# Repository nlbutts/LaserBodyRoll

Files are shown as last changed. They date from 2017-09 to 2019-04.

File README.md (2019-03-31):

# LaserBodyRoll

This product is designed to simulate wheel slip to prevent the front of a car from rising off the ground during hard acceleration. The device would be connected in between a wheel speed sensor and an engine ECU. Under normal conditions the device would pass through the wheel speed sensor directly to the engine ECU. If the front of the vehicle is detected rising off the ground, the system would increase the number of pulses per second (PPS) of the wheel to the engine ECU to simulate wheel slip. In theory, this should cause the engine ECU to reduce timing to prevent the simulated wheel slip and therefore reduce the front end from rising off the ground.
The system detects front end rise by using a laser rangefinder. The laser rangefinder can detect the small changes in distance from the mounting location to the ground. If the distance is increasing, then the system can increase the number of PPS from the wheel speed sensor to simulate the slip.

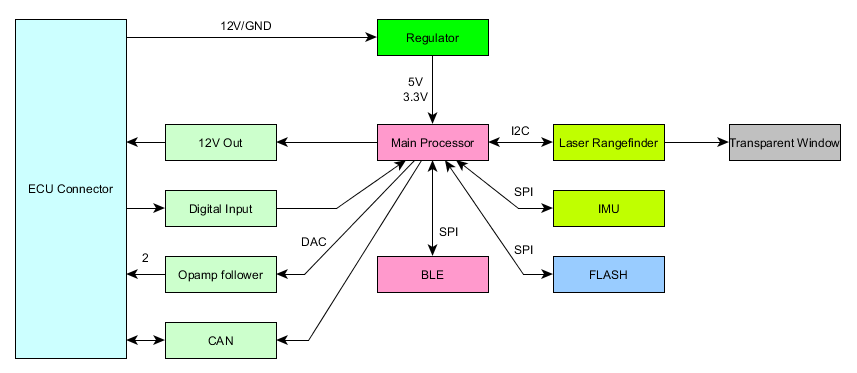
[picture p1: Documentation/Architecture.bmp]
Architecture High Level Architecture


# Hardware Connections
A single cable gland will be used to bring signals into and out of the ECU enclosure.

ECU Connector

| Wire | Description |
| --- | --- |
| Purple  | Power |
| Black  | Ground |
| Grey | Analog Out 1  |
| Red | Analog Out 2  |
| Brown  | DIN |
| Orange | DOUT |
| Yellow | CAN High |
| Green  | CAN Low |

The goal is to fit into this box enclosure

# Protocol between Processor and BLE
The PSoC and the Raspberry PI are connected via an SPI bus. The Pi is the SPI Master and the PSoC is a slave device. The packet that is transmitted to the PSOC is shown below

| Sync1 (8) | Sync2 (8) | Version (4)/Msg ID (4) | Length (8) | payload (2040) | CRC (8) |
| --- | --- | --- | --- | --- | --- |
| 0x55 | 0xAA | 0x01 / MSG ID | | | |

The number in parenthesis is how many bits are used for the various fields
The 4-bits of the version allows updates to the protocol. The 4-bits for the message ID allows
128 different message IDs. Length is the number of bytes in the payload 0-255 bytes.
The CRC is the CRC-8-CCITT using the following generator polynominal:
x^8 + x^2 + x + 1 (0x7)

| MSG ID | Description |
| --- | ---|
| 0 | Data input  |
| 1 | Data output |
| 2 | Main programming image |
| 3 | BLE programming image  |

Data input is a generic pass through message from the BLE interface to the main processor. The
data input is made up of an 8-bit UUID followed by the data item. Each data item has a unique
length, format, scale, etc. Data output is the same as data input, just going in the other
direction

| UUID | Description | Size (bytes) | Data type | Units |
| ---- | --- | --- | --- | ----- |
| 0 | Analog 1 slope | 4 | float | mm/mv |
| 1 | Analog 1 y offset | 4 | float | mv |
| 2 | Analog 2 slope | 4 | float | mm/mv |
| 3 | Analog 2 y offset | 4 | float | mv |
| 4 | Open drain pull up enbl | 1 | uint8 | bool  |
| 5 | Laser distance in mm | 2 | uint16 | mm |
| 6 | Accel X in mg | 2 | uint16 | mg |
| 7 | Accel Y in mg | 2 | uint16 | mg |
| 8 | Accel Z in mg | 2 | uint16 | mg |
| 9 | Gyro X in dps | 2 | uint16 | dps |
| 10 | Gyro Y in dps | 2 | uint16 | dps |
| 11 | Gyro Z in dps | 2 | uint16 | dps |
| 12 | Auto level gain | 4 | float | |
| 13 | EPOCH time | 4 | uint32 | epoch |
| 14 | Super cap voltage | 2 | uint32 | mv |

The main programming image is a LZMA compressed binary file. The BLE programming
image is an LZMA compressed cyacd file. Each BLE packet is only 23 bytes or so.
The programming images are transmitted with a byte counter as the first byte
of the payload. This allows a check that a packet hasn't been dropped and they are being
received in the correct order.

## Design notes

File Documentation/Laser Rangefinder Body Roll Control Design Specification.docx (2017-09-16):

# Laser Rangefinder Body Roll Control Design Specification

# Overview

This product is designed to simulate wheel slip to prevent the front of a car from rising off the ground during hard acceleration. The device would be connected in between a wheel speed sensor and an engine ECU. Under normal conditions the device would pass through the wheel speed sensor directly to the engine ECU. If the front of the vehicle is detected rising off the ground, the system would increase the number of pulses per second (PPS) of the wheel to the engine ECU to simulate wheel slip. In theory, this should cause the engine ECU to reduce timing to prevent the simulated wheel slip and therefore reduce the front end from rising off the ground.

The system detects front end rise by using a laser rangefinder. The laser rangefinder can detect the small changes in distance from the mounting location to the ground. If the distance is increasing, then the system can increase the number of PPS from the wheel speed sensor to simulate the slip.

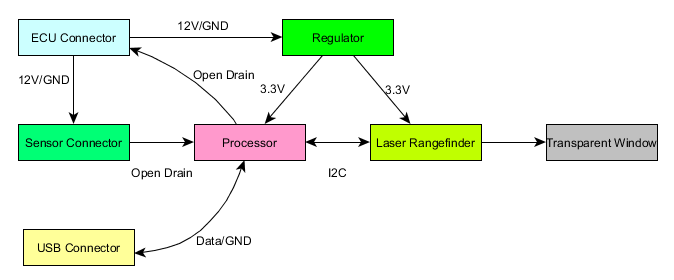
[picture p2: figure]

# Hardware Connections

The system will have three connectors: 1) to ECU connector, 2) to sensor connector, 3) USB connector. The ECU connector will supply power to the box, and provide the speed sensor signal back to the ECU. The sensor connector will provide power to the sensor and receive the PPS signal. The USB connector will be used for reprogramming and configuration.

ECU Connector

Pin | Description
1 | Power
2 | Ground
3 | Speed out
4 | Reserved

Sensor Connector

Pin | Description
1 | Power
2 | Ground
3 | Speed Input

USB Connector

Pin | Description
1 | VCC
2 | D-
3 | D+
4 | Ground

The device will consume no more than 1 watts of power (TBD). The device will be able to supply 0.5 watts to the sensor.

# Laser Rangefinder

A ST Microelectronics VL53L0 laser rangefinder. This device has a range of roughly 2 meters and can determine the distance down to a millimeter.

# Sensor Input/Output

The sensor input circuit will be able to handle an open drain style sensors. The sensor output system will drive an open drain style output.

# USB Port

The USB port will simulate a CDC interface and allow reprogramming of the device as well as configuration parameters.

Parameter | Description | Units
Distance Null Zone | Distance change to ignore from the laser rangefinder | Millimeters
Gain | Value multiplied by the change in distance to change in frequency
Averaging Filter | Long term averaging filter to capture baseline | Seconds

A PC tool will be written to allow these parameters to be changed.

# Theory of Operation

A long time filter will be used to determine the truth value of the ground. For example, over the course of 30 seconds the baseline distance will be determined. When the distance exceeds the Distance Null Zone, the Gain value will be multiplied by the difference between the Baseline value and the current distance value. This will be added to the current frequency of the wheel speed sensor.

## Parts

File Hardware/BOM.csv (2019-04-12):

Source: | C:\projects\LaserBodyRoll\Hardware\LaserBodyRoll.sch
Date: | 3/24/2019 14:10
Tool: | Eeschema (5.1.0)-1
Generator: | C:\Program Files\KiCad\bin\scripting\plugins/bom_csv_grouped_by_value.py
Component Count: | 42
Individual Components:
Item | Qty | Reference(s) | Value | LibPart | Footprint | Datasheet | Category | DK_Datasheet_Link | DK_Detail_Page | Description | Digi-Key_PN | Digikey | Family | MPN | Manufacturer | Partnum | Status
 |  | C1 | 10u | Device:C | Capacitors_SMD:C_0805_HandSoldering |  |  |  |  |  |  | 490-5523-1-ND |  |  |  | GRM21BR61E106KA73L
 |  | C2 | 10n | Device:C | Capacitors_SMD:C_0603_HandSoldering |  |  |  |  |  |  | 399-1092-1-ND |  |  |  | C0603C103J5RACTU
 |  | C3 | 10u | Device:C | Capacitors_SMD:C_0805_HandSoldering |  |  |  |  |  |  | 490-5523-1-ND |  |  |  | GRM21BR61E106KA73L
 |  | C4 | 0.1u | Device:C | Capacitors_SMD:C_0603_HandSoldering | ~
 |  | C5 | 22p | Device:C | Capacitors_SMD:C_0603_HandSoldering | ~
 |  | C6 | 22p | Device:C | Capacitors_SMD:C_0603_HandSoldering | ~
 |  | C7 | 0.1u | Device:C | Capacitors_SMD:C_0603_HandSoldering | ~
 |  | C8 | 0.1u | Device:C | Capacitors_SMD:C_0603_HandSoldering | ~
 |  | C9 | 0.1u | Device:C | Capacitors_SMD:C_0603_HandSoldering
 |  | C10 | 0.1u | Device:C | Capacitors_SMD:C_0603_HandSoldering | ~
 |  | C11 | 0.1u | Device:C | Capacitors_SMD:C_0603_HandSoldering
 |  | C12 | 2.2U | Device:C | Capacitors_SMD:C_0603_HandSoldering
 |  | C13 | 0.1u | Device:C | Capacitors_SMD:C_0603_HandSoldering
 |  | C14 | 10n | Device:C | Capacitors_SMD:C_0603_HandSoldering
 |  | C15 | 4.7u | Device:C | Capacitors_SMD:C_0603_HandSoldering
 |  | C16 | 0.1u | Device:C | Capacitors_SMD:C_0603_HandSoldering | ~
 |  | C17 | 0.1u | Device:C | Capacitors_SMD:C_0603_HandSoldering | ~
 |  | D1 | STPS2L40 | Device:D | Diodes_SMD:D_SMB |  |  |  |  |  |  | 497-5574-1-ND |  |  |  | STPS2L40U
 |  | D2 | D_TVS | Device:D_TVS | Diodes_SMD:D_SMB |  |  |  |  |  |  | 732-9779-1-ND |  |  |  | 824520201
 |  | D3 | D_TVS | Device:D_TVS | Diodes_SMD:D_SMB |  |  |  |  |  |  | 732-9779-1-ND |  |  |  | 824520201
 |  | D4 | D_Schottky | Device:D_Schottky | Diodes_SMD:D_SOD-123 |  |  |  |  |  |  | B0540W-FDICT-ND |  |  |  | B0540W-7-F
 |  | J1 | Conn_02x13_Odd_Even | Connector_Generic:Conn_02x13_Odd_Even | Pin_Headers:Pin_Header_Straight_2x13_Pitch2.54mm | ~
 |  | J2 | Conn_01x08 | Connector_Generic:Conn_01x08 | Pin_Headers:Pin_Header_Straight_1x08_Pitch2.54mm | ~
 |  | L1 | 4.7u | Device:L | Inductors_SMD:L_Taiyo-Yuden_MD-3030 |  |  |  |  |  |  | 490-15954-1-ND |  |  |  | LQH3NPN4R7MMEL
 |  | Q1 | Q_NPN_BCE | Device:Q_NPN_BCE | TO_SOT_Packages_SMD:SOT-23 |  |  |  |  |  |  | MMBT3904FSCT-ND
 |  | R1 | 24.3k | Device:R | Resistors_SMD:R_0603_HandSoldering
 |  | R2 | 24.3k | Device:R | Resistors_SMD:R_0603_HandSoldering
 |  | R3 | 24.3k | Device:R | Resistors_SMD:R_0603_HandSoldering
 |  | R4 | 49.9k | Device:R | Resistors_SMD:R_0603_HandSoldering
 |  | R5 | 9.53k | Device:R | Resistors_SMD:R_0603_HandSoldering
 |  | R6 | 10k | Device:R | Resistors_SMD:R_0603_HandSoldering
 |  | R7 | 10k | Device:R | Resistors_SMD:R_0603_HandSoldering
 |  | R8 | 120 | Device:R | Resistors_SMD:R_0603_HandSoldering | ~
 |  | R9 | 1k | Device:R | Resistors_SMD:R_0603_HandSoldering | ~
 |  | U1 | AOZ1280CI | dk_PMIC-Voltage-Regulators-DC-DC-Switching-Regulators:AOZ1280CI | digikey-footprints:SOT-23-6 | http://aosmd.com/res/data_sheets/AOZ1280CI.pdf | Integrated Circuits (ICs) | http://aosmd.com/res/data_sheets/AOZ1280CI.pdf | /product-detail/en/alpha-omega-semiconductor-inc/AOZ1280CI/785-1277-1-ND/2769845 | IC REG BUCK ADJ 1.2A SOT23-6 | 785-1277-1-ND |  | PMIC - Voltage Regulators - DC DC Switching Regulators | AOZ1280CI | Alpha & Omega Semiconductor Inc. |  | Active
 |  | U2 | ITS42K5D | General:ITS42K5D | KicadFootprint:PG-TSON-10 |  |  |  |  |  |  | ITS42K5DLDFXUMA1CT-ND |  |  |  | ITS42K5DLDFXUMA1
 |  | U3 | MCP47X | General:MCP47X | Housings_DFN_QFN:QFN-16-1EP_3x3mm_Pitch0.5mm |  |  |  |  |  |  | MCP47CVB22-E/MG-ND
 |  | U4 | ICM-20602 | General:ICM-20602 | Housings_DFN_QFN:QFN-16-1EP_3x3mm_Pitch0.5mm |  |  |  |  |  |  | 1428-1060-1-ND |  |  |  | ICM-20602
 |  | U5 | MCP25625 | General:MCP25625 | Housings_DFN_QFN:QFN-28-1EP_6x6mm_Pitch0.65mm |  |  |  |  |  |  | MCP25625T-E/MLCT-ND
 |  | U6 | VL53L0X | General:VL53L0X | KicadFootprint:VL53L0x |  |  |  |  |  |  | 497-16538-1-ND |  |  |  | VL53L0CXV0DH/1
 |  | U7 | LD3985 | General:LD3985 | TO_SOT_Packages_SMD:SOT-23-5_HandSoldering |  |  |  |  |  |  | 497-3504-1-ND
 |  | Y1 | 16MHz | Device:Crystal | Crystals:Crystal_SMD_5032-2pin_5.0x3.2mm_HandSoldering | ~
Collated Components:
Item | Qty | Reference(s) | Value | LibPart | Footprint | Datasheet | Category | DK_Datasheet_Link | DK_Detail_Page | Description | Digi-Key_PN | Digikey | Family | MPN | Manufacturer | Partnum | Status
1 | 2 | C1, C3 | 10u | Device:C | Capacitors_SMD:C_0805_HandSoldering |  |  |  |  |  |  | 490-5523-1-ND |  |  |  | GRM21BR61E106KA73L
2 | 2 | C2, C14 | 10n | Device:C | Capacitors_SMD:C_0603_HandSoldering |  |  |  |  |  |  | 399-1092-1-ND |  |  |  | C0603C103J5RACTU
3 | 9 | C4, C7, C8, C9, C10, C11, C13, C16, C17 | 0.1u | Device:C | Capacitors_SMD:C_0603_HandSoldering | ~
4 | 2 | C5, C6 | 22p | Device:C | Capacitors_SMD:C_0603_HandSoldering | ~
5 | 1 | C12 | 2.2U | Device:C | Capacitors_SMD:C_0603_HandSoldering
6 | 1 | C15 | 4.7u | Device:C | Capacitors_SMD:C_0603_HandSoldering
7 | 1 | D1 | STPS2L40 | Device:D | Diodes_SMD:D_SMB |  |  |  |  |  |  | 497-5574-1-ND |  |  |  | STPS2L40U
8 | 2 | D2, D3 | D_TVS | Device:D_TVS | Diodes_SMD:D_SMB |  |  |  |  |  |  | 732-9779-1-ND |  |  |  | 824520201
9 | 1 | D4 | D_Schottky | Device:D_Schottky | Diodes_SMD:D_SOD-123 |  |  |  |  |  |  | B0540W-FDICT-ND |  |  |  | B0540W-7-F
10 | 1 | J1 | Conn_02x13_Odd_Even | Connector_Generic:Conn_02x13_Odd_Even | Pin_Headers:Pin_Header_Straight_2x13_Pitch2.54mm | ~
11 | 1 | J2 | Conn_01x08 | Connector_Generic:Conn_01x08 | Pin_Headers:Pin_Header_Straight_1x08_Pitch2.54mm | ~
12 | 1 | L1 | 4.7u | Device:L | Inductors_SMD:L_Taiyo-Yuden_MD-3030 |  |  |  |  |  |  | 490-15954-1-ND |  |  |  | LQH3NPN4R7MMEL
13 | 1 | Q1 | Q_NPN_BCE | Device:Q_NPN_BCE | TO_SOT_Packages_SMD:SOT-23 |  |  |  |  |  |  | MMBT3904FSCT-ND
14 | 3 | R1, R2, R3 | 24.3k | Device:R | Resistors_SMD:R_0603_HandSoldering
15 | 1 | R4 | 49.9k | Device:R | Resistors_SMD:R_0603_HandSoldering
16 | 1 | R5 | 9.53k | Device:R | Resistors_SMD:R_0603_HandSoldering
17 | 2 | R6, R7 | 10k | Device:R | Resistors_SMD:R_0603_HandSoldering
18 | 1 | R8 | 120 | Device:R | Resistors_SMD:R_0603_HandSoldering | ~
19 | 1 | R9 | 1k | Device:R | Resistors_SMD:R_0603_HandSoldering | ~
20 | 1 | U1 | AOZ1280CI | dk_PMIC-Voltage-Regulators-DC-DC-Switching-Regulators:AOZ1280CI | digikey-footprints:SOT-23-6 | http://aosmd.com/res/data_sheets/AOZ1280CI.pdf | Integrated Circuits (ICs) | http://aosmd.com/res/data_sheets/AOZ1280CI.pdf | /product-detail/en/alpha-omega-semiconductor-inc/AOZ1280CI/785-1277-1-ND/2769845 | IC REG BUCK ADJ 1.2A SOT23-6 | 785-1277-1-ND |  | PMIC - Voltage Regulators - DC DC Switching Regulators | AOZ1280CI | Alpha & Omega Semiconductor Inc. |  | Active
21 | 1 | U2 | ITS42K5D | General:ITS42K5D | KicadFootprint:PG-TSON-10 |  |  |  |  |  |  | ITS42K5DLDFXUMA1CT-ND |  |  |  | ITS42K5DLDFXUMA1
22 | 1 | U3 | MCP47X | General:MCP47X | Housings_DFN_QFN:QFN-16-1EP_3x3mm_Pitch0.5mm |  |  |  |  |  |  | MCP47CVB22-E/MG-ND
23 | 1 | U4 | ICM-20602 | General:ICM-20602 | Housings_DFN_QFN:QFN-16-1EP_3x3mm_Pitch0.5mm |  |  |  |  |  |  | 1428-1060-1-ND |  |  |  | ICM-20602
24 | 1 | U5 | MCP25625 | General:MCP25625 | Housings_DFN_QFN:QFN-28-1EP_6x6mm_Pitch0.65mm |  |  |  |  |  |  | MCP25625T-E/MLCT-ND
25 | 1 | U6 | VL53L0X | General:VL53L0X | KicadFootprint:VL53L0x |  |  |  |  |  |  | 497-16538-1-ND |  |  |  | VL53L0CXV0DH/1
26 | 1 | U7 | LD3985 | General:LD3985 | TO_SOT_Packages_SMD:SOT-23-5_HandSoldering |  |  |  |  |  |  | 497-3504-1-ND
27 | 1 | Y1 | 16MHz | Device:Crystal | Crystals:Crystal_SMD_5032-2pin_5.0x3.2mm_HandSoldering | ~

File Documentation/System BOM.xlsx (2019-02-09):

Source: | C:\projects\LaserBodyRoll\Hardware\LaserBodyRoll.sch
Date: | 2018-03-07 05:57
Tool: | Eeschema (2017-09-19 revision dddaa7e69)-makepkg
Generator: | bom_csv_grouped_by_value.py
Component Count: | 84
Individual Components:
Item | Qty | Reference(s) | Manufacturer | Value | Footprint | Datasheet | Digikey | Partnum
 |  | C1 |  | 10u | Capacitors_SMD:C_0603 |  | 490-12737-1-ND
 |  | C2 |  | 3.3n | Capacitors_SMD:C_0603 |  | 1276-1790-1-ND | CL10C3R3CB8NNNC
 |  | C3 |  | 22u | SMD_Packages:SMD-1210_Pol |  | 478-9063-1-ND | TPSB226K006R0375
 |  | C4 |  | 1u | Capacitors_SMD:C_0603
 |  | C5 |  | 2.2U | Capacitors_SMD:C_0603
 |  | C6 |  | 20p | Capacitors_SMD:C_0603
 |  | C7 |  | 20p | Capacitors_SMD:C_0603
 |  | C8 |  | 6.8 | Capacitors_SMD:C_0603
 |  | C9 |  | 6.8 | Capacitors_SMD:C_0603
 |  | C10 |  | 1.5F | KicadFootprint:Elna_Dynacap |  | 604-1151-ND | DB-5R5D155T
 |  | C11 |  | 4.7u | Capacitors_SMD:C_0603
 |  | C12 |  | 100n | Capacitors_SMD:C_0603
 |  | C13 |  | 100n | Capacitors_SMD:C_0603
 |  | C14 |  | 100n | Capacitors_SMD:C_0603
 |  | C15 |  | 100n | Capacitors_SMD:C_0603
 |  | C16 |  | 1u | Capacitors_SMD:C_0603
 |  | C17 |  | 10n | Capacitors_SMD:C_0603
 |  | C18 |  | 10n | Capacitors_SMD:C_0603
 |  | C19 |  | 10n | Capacitors_SMD:C_0603
 |  | C20 |  | 0.1n | Capacitors_SMD:C_0603
 |  | C21 |  | 0.1u | Capacitors_SMD:C_0603_HandSoldering
 |  | C22 |  | 0.1u | Capacitors_SMD:C_0603_HandSoldering
 |  | C23 |  | 1u | Capacitors_SMD:C_0603_HandSoldering
 |  | C24 |  | 0.1u | Capacitors_SMD:C_0603
 |  | C25 |  | 2.2U | Capacitors_SMD:C_0603
 |  | C26 |  | 10n | Capacitors_SMD:C_0603
 |  | C27 |  | 4.7u | Capacitors_SMD:C_0603
 |  | D1 |  | STPS2L40 | Diodes_SMD:D_SMB |  | 497-5574-1-ND | STPS2L40U
 |  | D2 |  | D_TVS | Diodes_SMD:D_SMB |  | 732-9779-1-ND | 824520201
 |  | D3 |  | D | Diodes_SMD:D_SOD-123 |  | B0540W-FDICT-ND | B0540W-7-F
 |  | D4 |  | D_Zener | Diodes_SMD:D_SMB |  | MMSZ5232B-FDICT-ND | MMSZ5232B
 |  | D5 |  | D_Zener | Diodes_SMD:D_SMB |  | MMSZ5232B-FDICT-ND | MMSZ5232B
 |  | D6 |  | D_TVS | Diodes_SMD:D_SMB |  | 732-9779-1-ND | 824520201
 |  | D7 |  | LED_RABG | KicadFootprint:CREE_PLCC4 |  | CLV1L-FKB-CHMMQEHBB7673673CT-ND | CLV1L-FKB-CHMMQEHBB7673673
 |  | D8 |  | LED_RABG | KicadFootprint:CREE_PLCC4 |  | CLV1L-FKB-CHMMQEHBB7673673CT-ND | CLV1L-FKB-CHMMQEHBB7673673
 |  | J2 |  | FTSH-105-01-L-DV-K | KicadFootprint:FTSH-105-01-L-DV-K |  | SAM8799-ND
 |  | J3 |  | FTSH-105-01-L-DV-K | KicadFootprint:FTSH-105-01-L-DV-K |  | SAM8799-ND
 |  | J4 |  | Conn_01x08 | Pin_Headers:Pin_Header_Straight_1x08_Pitch2.54mm
 |  | L1 |  | L_Core_Ferrite | Inductors_SMD:L_0805 |  | 490-5988-1-ND | BLM21PG331SN1D
 |  | Q1 |  | Q_NPN_BCE | TO_SOT_Packages_SMD:SOT-23 |  | MMBT3904FSCT-ND
 |  | R1 |  | 525k | Resistors_SMD:R_0805 |  | 311-523KHRCT-ND
 |  | R2 |  | 100k | Resistors_SMD:R_0805 |  | P100KGCT-ND
 |  | R3 |  | 360 | Resistors_SMD:R_0603
 |  | R4 |  | 120 | Resistors_SMD:R_0603
 |  | R5 |  | 0 | Resistors_SMD:R_0603
 |  | R6 |  | 0 | Resistors_SMD:R_0603
 |  | R7 |  | 0 | Resistors_SMD:R_0603
 |  | R8 |  | 0 | Resistors_SMD:R_0603
 |  | R9 |  | 10k | Resistors_SMD:R_0603
 |  | R10 |  | 75k | Resistors_SMD:R_0603
 |  | R11 |  | 24.3k | Resistors_SMD:R_0603 |  | P10KGCT-ND
 |  | R12 |  | 24.3k | Resistors_SMD:R_0603
 |  | R13 |  | 24.3k | Resistors_SMD:R_0603
 |  | R14 |  | 24.3k | Resistors_SMD:R_0603 |  | 311-30KGRCT-ND
 |  | R15 |  | 24.3k | Resistors_SMD:R_0603 |  | 311-24.3KHRCT-ND
 |  | R16 |  | 24.3k | Resistors_SMD:R_0603
 |  | R17 |  | 24.3k | Resistors_SMD:R_0603
 |  | R18 |  | 24.3k | Resistors_SMD:R_0603
 |  | R19 |  | 24.3k | Resistors_SMD:R_0603
 |  | R20 |  | 330 | Resistors_SMD:R_0603
 |  | R21 |  | 330 | Resistors_SMD:R_0603
 |  | R22 |  | 330 | Resistors_SMD:R_0603
 |  | R23 |  | 1.7k | Resistors_SMD:R_0603
 |  | R24 |  | 1.7k | Resistors_SMD:R_0603
 |  | R25 |  | 10k | Resistors_SMD:R_0603
 |  | R26 |  | 10k | Resistors_SMD:R_0603
 |  | R27 |  | 25 | Resistors_SMD:R_0603
 |  | R28 |  | 330 | Resistors_SMD:R_0603
 |  | R29 |  | 330 | Resistors_SMD:R_0603
 |  | R30 |  | 330 | Resistors_SMD:R_0603
 |  | R31 |  | 120 | Resistors_SMD:R_0603
 |  | U1 |  | TPS821XX | KicadFootprint:TPS821XX |  | 296-47090-1-ND | TPS82150
 |  | U2 |  | LDK130-ADJ_SOT23_SOT353 | TO_SOT_Packages_SMD:SOT-353_SC-70-5 |  | 497-14023-2-ND | LDK130-M-R
 |  | U3 |  | STM32F303RETx | Housings_QFP:TQFP-64_10x10mm_Pitch0.5mm |  | 604-1151-ND | DB-5R5D155T
 |  | U4 |  | LMC6032 | SMD_Packages:SOIC-8-N |  | LMC6032IMX/NOPBDKR-ND | LMC6032IMX/NOPB
 |  | U5 |  | ITS42K5D | KicadFootprint:PG-TSON-10 |  | ITS42K5DLDFXUMA1CT-ND | ITS42K5DLDFXUMA1
 |  | U6 |  | CYBLE-022001-00 | KicadFootprint:CYBLE-022001 |  | 428-3408-1-ND | CYBLE-022001-00
 |  | U7 |  | TJA1051T-3 | Housings_SOIC:SOIC-8_3.9x4.9mm_Pitch1.27mm |  | 568-8684-1-ND | TJA1051T/3,118
 |  | U8 |  | ICM-20602 | KicadFootprint:QFN-16-no_center_3x3mm_Pitch0.5mm |  | 1428-1060-1-ND | ICM-20602
 |  | U9 |  | W25Qxx | Housings_SOIC:SOIC-8_3.9x4.9mm_Pitch1.27mm |  | W25Q64JVSSIQ-ND | W25Q64JVSSIQ
 |  | U10 |  | VL53L0X | KicadFootprint:VL53L0x |  | 497-16538-1-ND | VL53L0CXV0DH/1
 |  | W1 |  | TEST_1P | Connectors_TestPoints:Test_Point_Pad_d2.0mm
 |  | Y1 |  | 8MHz | Crystals:Crystal_SMD_MicroCrystal_CC4V-T1A-2pin_5.0x1.9mm_HandSoldering |  | 535-10630-1-ND | ABM3-8.000MHZ-D2Y-T
 |  | Y2 |  | 32.768 | Crystals:Crystal_SMD_MicroCrystal_CC7V-T1A-2pin_3.2x1.5mm_HandSoldering |  | 1253-1112-1-ND | ST3215SB32768B0HPWB3
 |  |  | Bud Industries |  |  |  | 377-1255-ND | PN-1321-C

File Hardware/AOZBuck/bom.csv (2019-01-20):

Source: | C:\projects\LaserBodyRoll\Hardware\AOZBuck\AOZBuck.sch
Date: | 6/24/2018 8:24:19 AM
Tool: | Eeschema (2017-09-19 revision dddaa7e69)-makepkg
Generator: | bom_csv_grouped_by_value.py
Component Count: | 10
Individual Components:
Item | Qty | Reference(s) | Value | LibPart | Footprint | Datasheet | Category | DK_Datasheet_Link | DK_Detail_Page | Description | Digi-Key_PN | Digikey | Family | MPN | Manufacturer | Partnum | Status
 |  | C1 | 10u | device:C | Capacitors_SMD:C_0805_HandSoldering |  |  |  |  |  |  | 490-5523-1-ND |  |  |  | GRM21BR61E106KA73L
 |  | C2 | 10n | device:C | Capacitors_SMD:C_0603_HandSoldering |  |  |  |  |  |  | 399-1092-1-ND |  |  |  | C0603C103J5RACTU
 |  | C3 | 10u | device:C | Capacitors_SMD:C_0805_HandSoldering |  |  |  |  |  |  | 490-5523-1-ND |  |  |  | GRM21BR61E106KA73L
 |  | D1 | D_Schottky | device:D_Schottky | Diodes_SMD:D_SOD-123 |  |  |  |  |  |  | B0540W-FDICT-ND |  |  |  | B0540W-7-F
 |  | J1 | Conn_01x02 | conn:Conn_01x02 | Pin_Headers:Pin_Header_Straight_1x02_Pitch2.54mm
 |  | J2 | Conn_01x02 | conn:Conn_01x02 | Pin_Headers:Pin_Header_Straight_1x02_Pitch2.54mm
 |  | L1 | 4.7u | device:L | Inductors_SMD:L_Taiyo-Yuden_MD-3030 |  |  |  |  |  |  | 490-15954-1-ND |  |  |  | LQH3NPN4R7MMEL
 |  | R1 | 49.9k | device:R | Resistors_SMD:R_0603_HandSoldering
 |  | R2 | 9.53k | device:R | Resistors_SMD:R_0603_HandSoldering
 |  | U1 | AOZ1280CI | dk_PMIC-Voltage-Regulators-DC-DC-Switching-Regulators:AOZ1280CI | digikey-footprints:SOT-23-6 | http://aosmd.com/res/data_sheets/AOZ1280CI.pdf | Integrated Circuits (ICs) | http://aosmd.com/res/data_sheets/AOZ1280CI.pdf | /product-detail/en/alpha-omega-semiconductor-inc/AOZ1280CI/785-1277-1-ND/2769845 | IC REG BUCK ADJ 1.2A SOT23-6 | 785-1277-1-ND |  | PMIC - Voltage Regulators - DC DC Switching Regulators | AOZ1280CI | Alpha & Omega Semiconductor Inc. |  | Active
Collated Components:
Item | Qty | Reference(s) | Value | LibPart | Footprint | Datasheet | Category | DK_Datasheet_Link | DK_Detail_Page | Description | Digi-Key_PN | Digikey | Family | MPN | Manufacturer | Partnum | Status
1 | 2 | C1, C3 | 10u | device:C | Capacitors_SMD:C_0805_HandSoldering |  |  |  |  |  |  | 490-5523-1-ND |  |  |  | GRM21BR61E106KA73L
2 | 1 | C2 | 10n | device:C | Capacitors_SMD:C_0603_HandSoldering |  |  |  |  |  |  | 399-1092-1-ND |  |  |  | C0603C103J5RACTU
3 | 1 | D1 | D_Schottky | device:D_Schottky | Diodes_SMD:D_SOD-123 |  |  |  |  |  |  | B0540W-FDICT-ND |  |  |  | B0540W-7-F
4 | 2 | J1, J2 | Conn_01x02 | conn:Conn_01x02 | Pin_Headers:Pin_Header_Straight_1x02_Pitch2.54mm
5 | 1 | L1 | 4.7u | device:L | Inductors_SMD:L_Taiyo-Yuden_MD-3030 |  |  |  |  |  |  | 490-15954-1-ND |  |  |  | LQH3NPN4R7MMEL
6 | 1 | R1 | 49.9k | device:R | Resistors_SMD:R_0603_HandSoldering
7 | 1 | R2 | 9.53k | device:R | Resistors_SMD:R_0603_HandSoldering
8 | 1 | U1 | AOZ1280CI | dk_PMIC-Voltage-Regulators-DC-DC-Switching-Regulators:AOZ1280CI | digikey-footprints:SOT-23-6 | http://aosmd.com/res/data_sheets/AOZ1280CI.pdf | Integrated Circuits (ICs) | http://aosmd.com/res/data_sheets/AOZ1280CI.pdf | /product-detail/en/alpha-omega-semiconductor-inc/AOZ1280CI/785-1277-1-ND/2769845 | IC REG BUCK ADJ 1.2A SOT23-6 | 785-1277-1-ND |  | PMIC - Voltage Regulators - DC DC Switching Regulators | AOZ1280CI | Alpha & Omega Semiconductor Inc. |  | Active

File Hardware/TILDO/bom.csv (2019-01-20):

Source: | C:\projects\LaserBodyRoll\Hardware\TILDO\TI_HV_LDO.sch
Date: | 6/24/2018 4:46:14 PM
Tool: | Eeschema (2017-09-19 revision dddaa7e69)-makepkg
Generator: | bom_csv_grouped_by_value.py
Component Count: | 10
Individual Components:
Item | Qty | Reference(s) | Value | LibPart | Footprint | Datasheet
 |  | C1 | 22u | device:C | Capacitors_SMD:C_1210_HandSoldering
 |  | C2 | 10u | device:C | Capacitors_SMD:C_0805_HandSoldering
 |  | C3 | 10u | device:C | Capacitors_SMD:C_0805_HandSoldering
 |  | J1 | Conn_01x02 | conn:Conn_01x02 | Pin_Headers:Pin_Header_Straight_1x02_Pitch2.54mm
 |  | J2 | Conn_01x02 | conn:Conn_01x02 | Pin_Headers:Pin_Header_Straight_1x02_Pitch2.54mm
 |  | J3 | Conn_01x02 | conn:Conn_01x02 | Pin_Headers:Pin_Header_Straight_1x02_Pitch2.54mm
 |  | R1 | 10k | device:R | Resistors_SMD:R_0603_HandSoldering
 |  | R2 | 30k | device:R | Resistors_SMD:R_0603_HandSoldering
 |  | R3 | 10k | device:R | Resistors_SMD:R_0603_HandSoldering
 |  | U1 | TPS7A19 | General:TPS7A19 | Housings_DFN_QFN:DFN-8-1EP_3x3mm_Pitch0.65mm
Collated Components:
Item | Qty | Reference(s) | Value | LibPart | Footprint | Datasheet
1 | 1 | C1 | 22u | device:C | Capacitors_SMD:C_1210_HandSoldering
2 | 2 | C2, C3 | 10u | device:C | Capacitors_SMD:C_0805_HandSoldering
3 | 3 | J1, J2, J3 | Conn_01x02 | conn:Conn_01x02 | Pin_Headers:Pin_Header_Straight_1x02_Pitch2.54mm
4 | 2 | R1, R3 | 10k | device:R | Resistors_SMD:R_0603_HandSoldering
5 | 1 | R2 | 30k | device:R | Resistors_SMD:R_0603_HandSoldering
6 | 1 | U1 | TPS7A19 | General:TPS7A19 | Housings_DFN_QFN:DFN-8-1EP_3x3mm_Pitch0.65mm

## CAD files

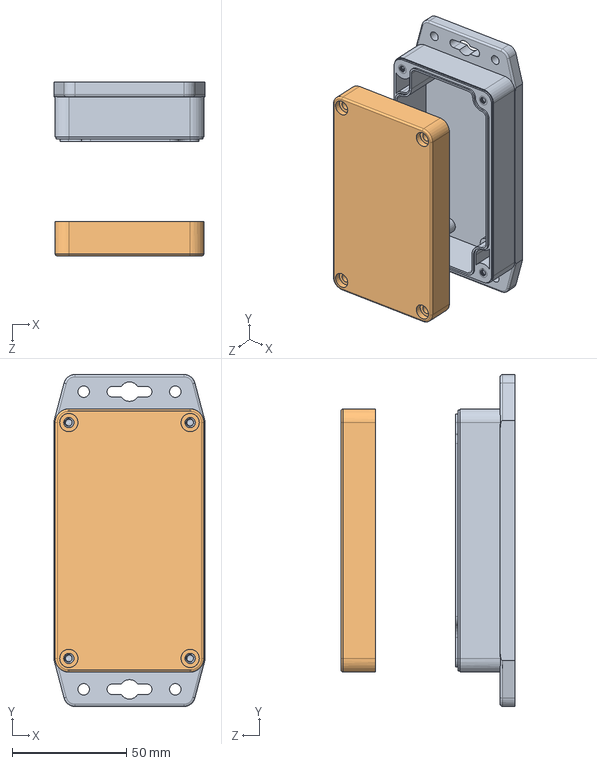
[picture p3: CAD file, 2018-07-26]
Mechanical/BUD Box.SLDASM
65.8 x 145.0 x 76.0 mm
Base
Cover

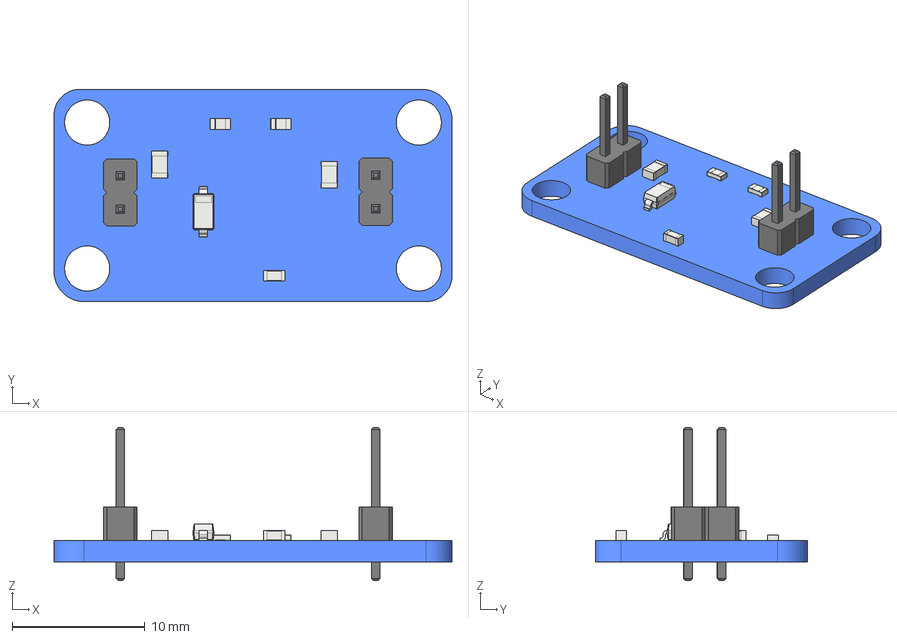
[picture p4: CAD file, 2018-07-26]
Hardware/AOZBuck/AOZBuck.FCStd
30.0 x 16.0 x 11.5 mm
Pcb
C_0603_
D_SOD_123_
Pin_Header_Straight_1x02_Pitch254mm_
Pin_Header_Straight_1x02_Pitch254mm_001
R_0603_
R_0603_001
C_0805_
C_0805_001

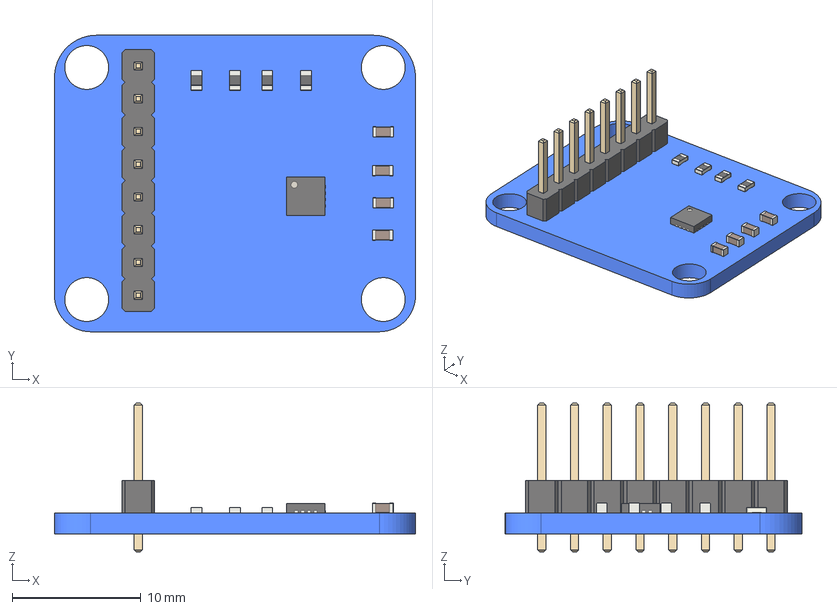
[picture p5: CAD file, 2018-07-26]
Hardware/IMU/IMU_Board.step
28.0 x 23.0 x 11.5 mm

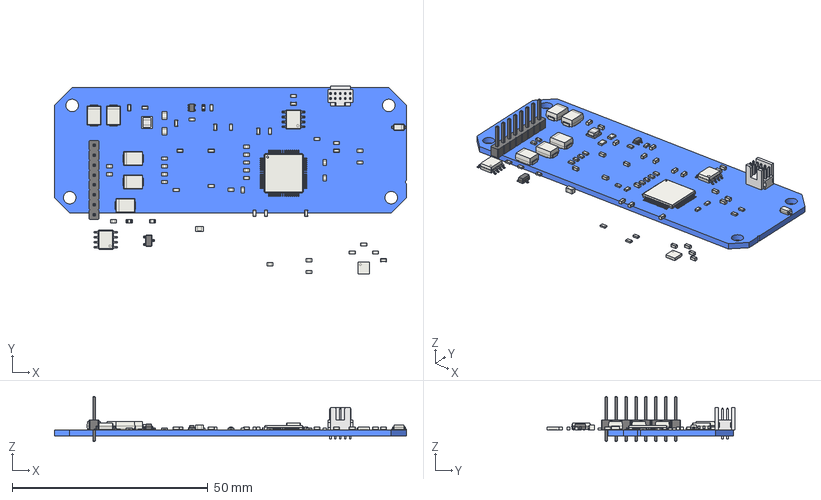
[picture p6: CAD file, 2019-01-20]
Hardware/LaserBodyRoll1.FCStd
90.0 x 48.0 x 11.5 mm
Pcb
SOT_353_SC_70_5_
C_0603_
C_0603_001
C_0603_002
C_0603_003
C_0603_004
R_0603_
R_0603_001
R_0603_002
R_0603_003
FTSH-105-01-L-D-K_
SOT_23_
C_0603_005
C_0603_006
C_0603_007
C_0603_008
C_0603_009
C_0603_010
C_0603_011
C_0603_012
C_0603_013
C_0603_014
D_SMB_
D_SOD_123_
R_0805_
R_0805_001
R_0603_004
R_0603_005
R_0603_006
R_0603_007
R_0603_008
R_0603_009
R_0603_010
R_0603_011
R_0603_012
R_0603_013
R_0603_014
R_0603_015
R_0603_016
R_0603_017
R_0603_018
R_0603_019
R_0603_020
R_0603_021
SIL0008D_
C_0603_015
C_0603_016
C_0603_017
C_0603_018
C_0603_019
C_0603_020
C_0603_021
C_0603_022
C_0603_023
C_0603_024
D_SMB_001
D_SMB_002
D_SMB_003
D_SMB_004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

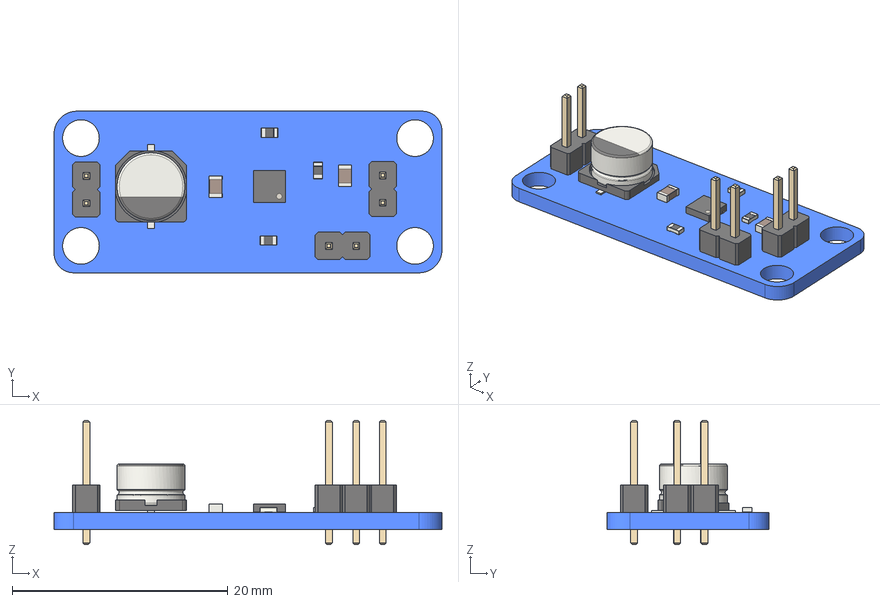
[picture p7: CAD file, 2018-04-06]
Hardware/TILDO/TI_HV_LDO.step
36.0 x 15.0 x 11.5 mm
Pcb
Pin_Header_Straight_1x02_Pitch254mm_
Pin_Header_Straight_1x02_Pitch254mm_001
CP_Elec_6.3x4.5_
C_0805_
C_0805_001
Pin_Header_Straight_1x02_Pitch254mm_002
R_0603_
R_0603_001
R_0603_002
DFN-8-1EP_3x3mm_Pitch0.65mm_

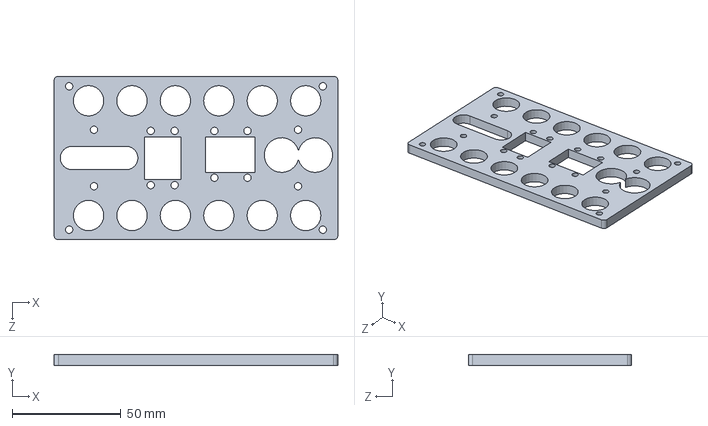
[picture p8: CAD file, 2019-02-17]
Mechanical/Bottom PCB Holder v2.SLDPRT
130.8 x 5.00 x 75.3 mm

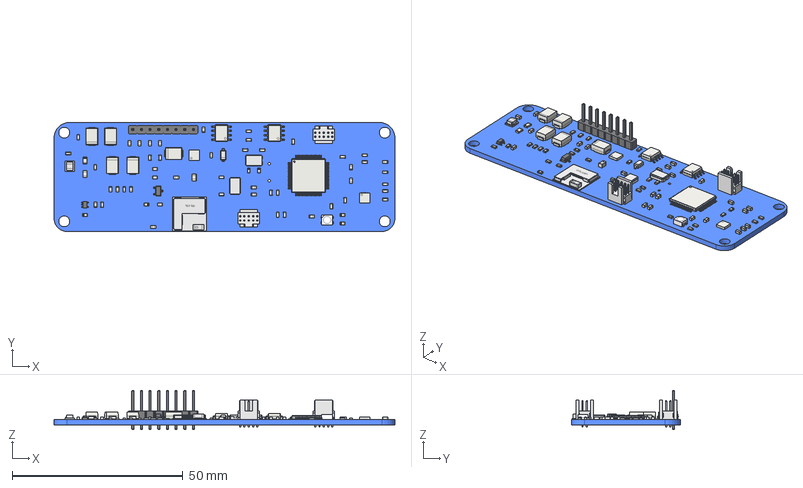
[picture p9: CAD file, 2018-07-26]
Hardware/LaserBodyRoll.FCStd
100.0 x 32.0 x 11.5 mm
Pcb
R_0603_
R_0603_001
R_0603_002
R_0603_003
SOT_353_SC_70_5_
C_0603_
C_0603_001
C_0603_002
C_0603_003
C_0603_004
R_0603_004
R_0603_005
R_0603_006
R_0603_007
FTSH-105-01-L-D-K_
SOT_23_
C_0603_005
C_0603_006
C_0603_007
C_0603_008
C_0603_009
C_0603_010
C_0603_011
C_0603_012
C_0603_013
C_0603_014
D_SMB_
D_SOD_123_
R_0805_
R_0805_001
R_0603_008
R_0603_009
R_0603_010
R_0603_011
R_0603_012
R_0603_013
R_0603_014
R_0603_015
R_0603_016
R_0603_017
R_0603_018
R_0603_019
R_0603_020
R_0603_021
R_0603_022
R_0603_023
R_0603_024
R_0603_025
SIL0008D_
C_0603_015
C_0603_016
C_0603_017
C_0603_018
C_0603_019
C_0603_020
C_0603_021
C_0603_022
C_0603_023
C_0603_024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

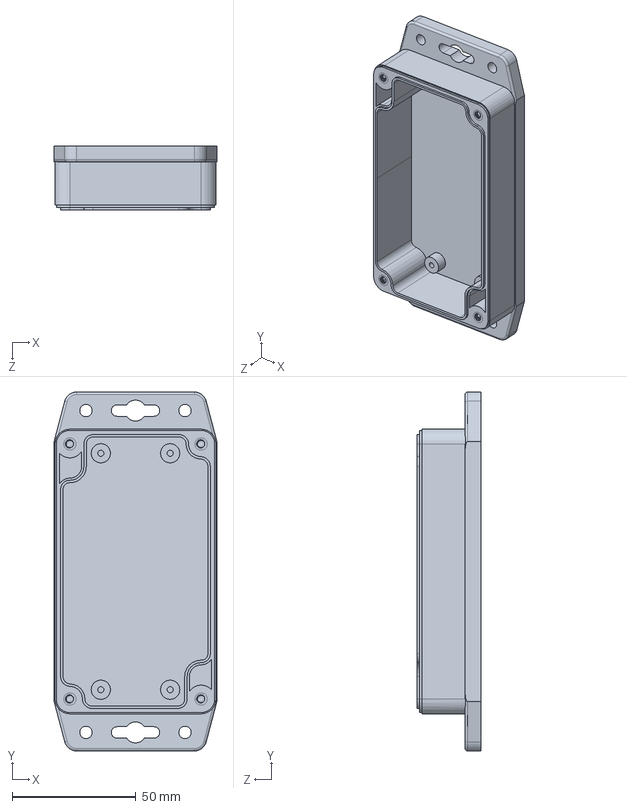
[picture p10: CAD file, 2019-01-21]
Mechanical/Base.sldprt
65.8 x 145.0 x 26.0 mm

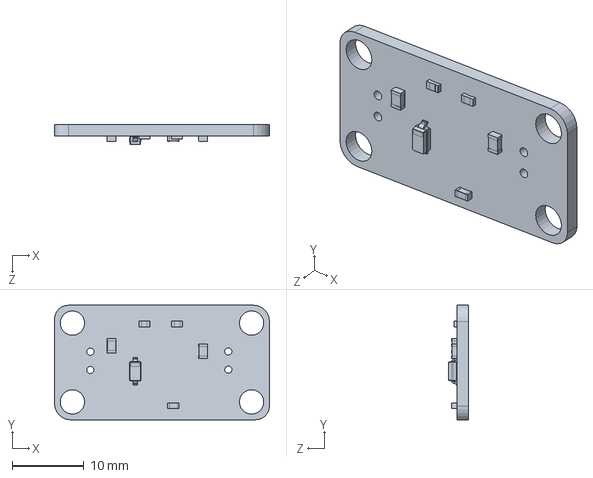
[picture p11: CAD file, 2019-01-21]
Mechanical/AOZBuck1.SLDPRT
30.0 x 16.0 x 2.85 mm

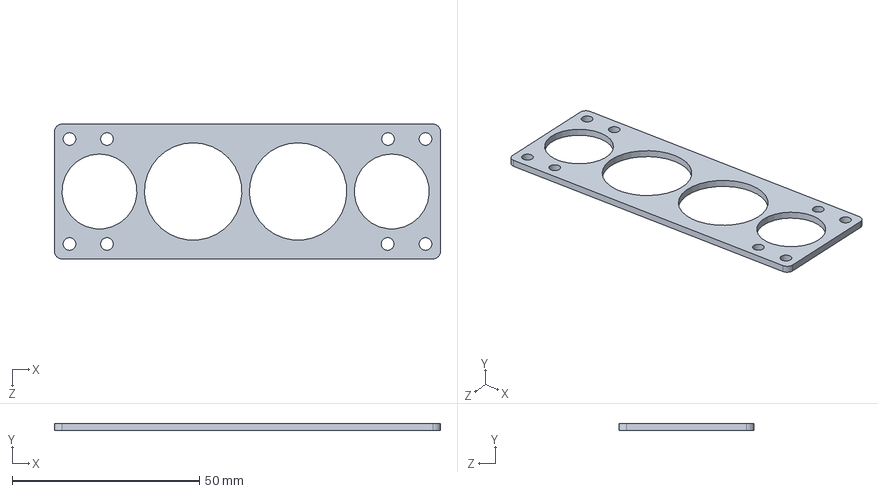
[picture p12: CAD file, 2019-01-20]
Mechanical/Top PCB Holder.SLDPRT
103.0 x 2.00 x 36.0 mm

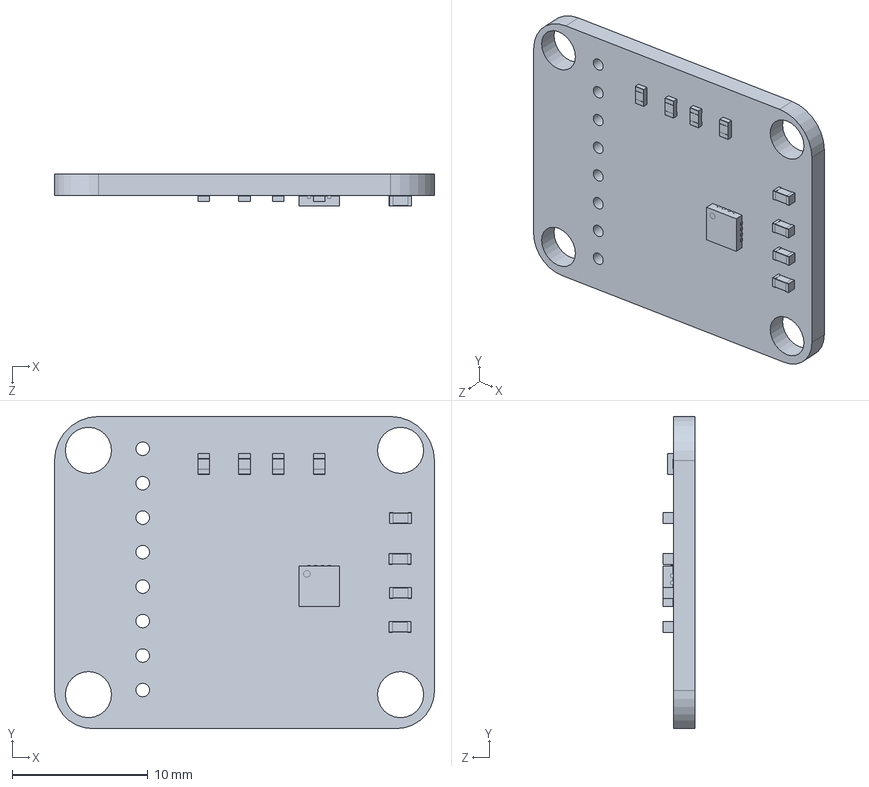
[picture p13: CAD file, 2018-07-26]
Mechanical/IMU_Board.SLDPRT
28.0 x 23.0 x 2.38 mm

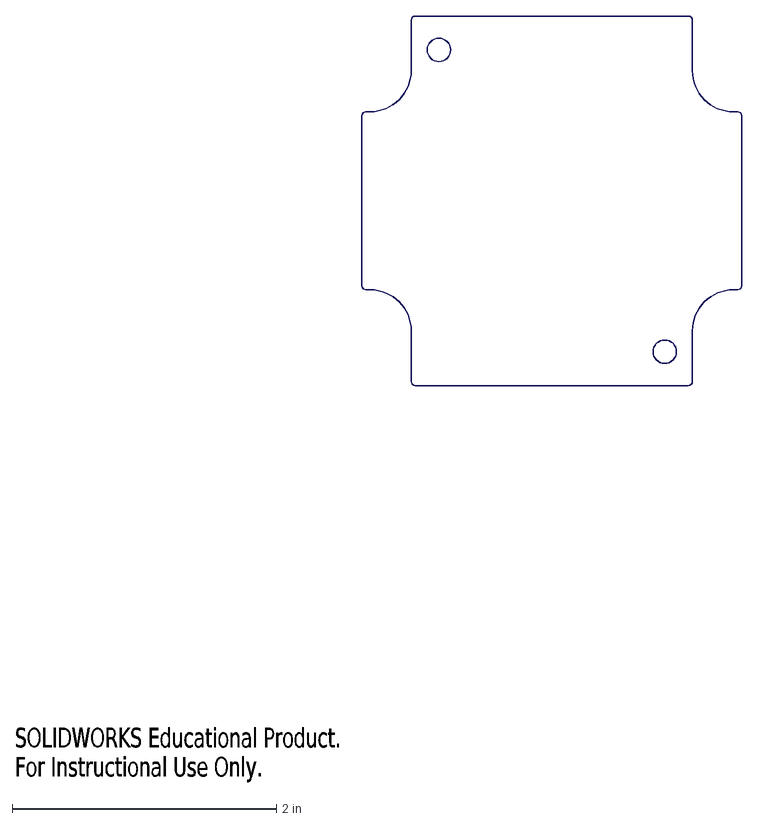
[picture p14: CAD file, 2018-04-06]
Mechanical/big_board_outline.dxf
SOLIDWORKS Educational Product.
For Instructional Use Only.

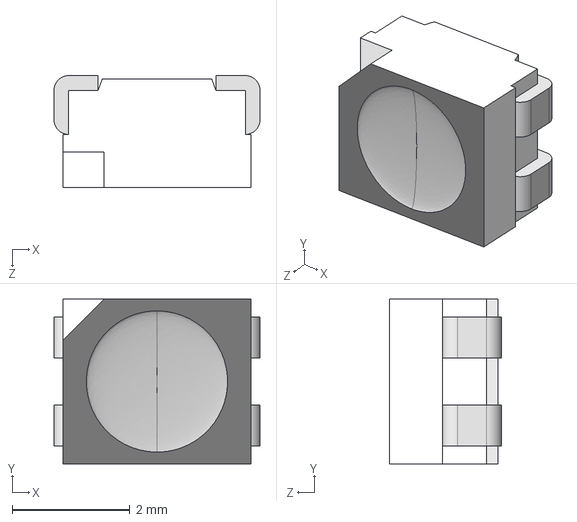
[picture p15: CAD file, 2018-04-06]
Mechanical/CLV1AFKB(Светодиод RGB).STEP
3.50 x 2.80 x 1.90 mm

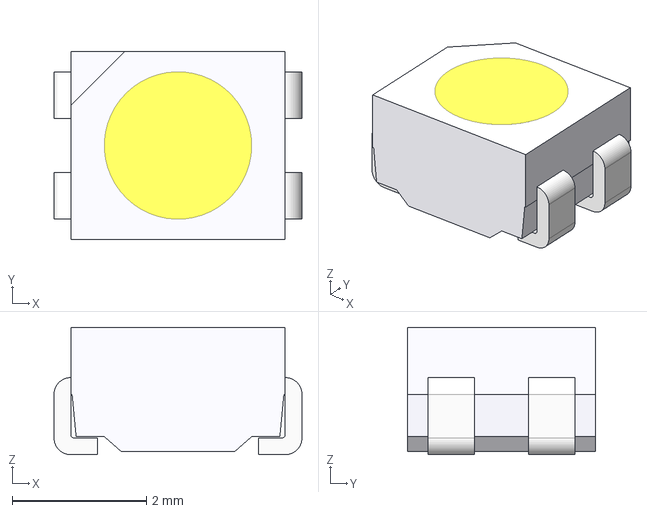
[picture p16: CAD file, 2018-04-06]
Mechanical/PZ_LED_SMD_PLCC4.stp
3.70 x 2.80 x 1.90 mm

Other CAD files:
Hardware/AOZBuck/AOZBuck1.step
Mechanical/Cover.sldprt
Mechanical/Board Outline.FCStd
Mechanical/BUD PN-1312.step
Hardware/AOZBuck/AOZBuck1.FCStd
Hardware/IMU/IMU_Board.FCStd
Hardware/TILDO/TI_HV_LDO.FCStd
Mechanical/Bottom PCB Holder v2.STL
Mechanical/Bottom PCB Holder.SLDPRT
Mechanical/Bottom PCB Holder.STL
Mechanical/FTSH-105-01-L-D-K.stp
Mechanical/Raspberry Pi Zero Outline.FCStd
Mechanical/Top PCB Holder.STL
Mechanical/board_outline.dxf

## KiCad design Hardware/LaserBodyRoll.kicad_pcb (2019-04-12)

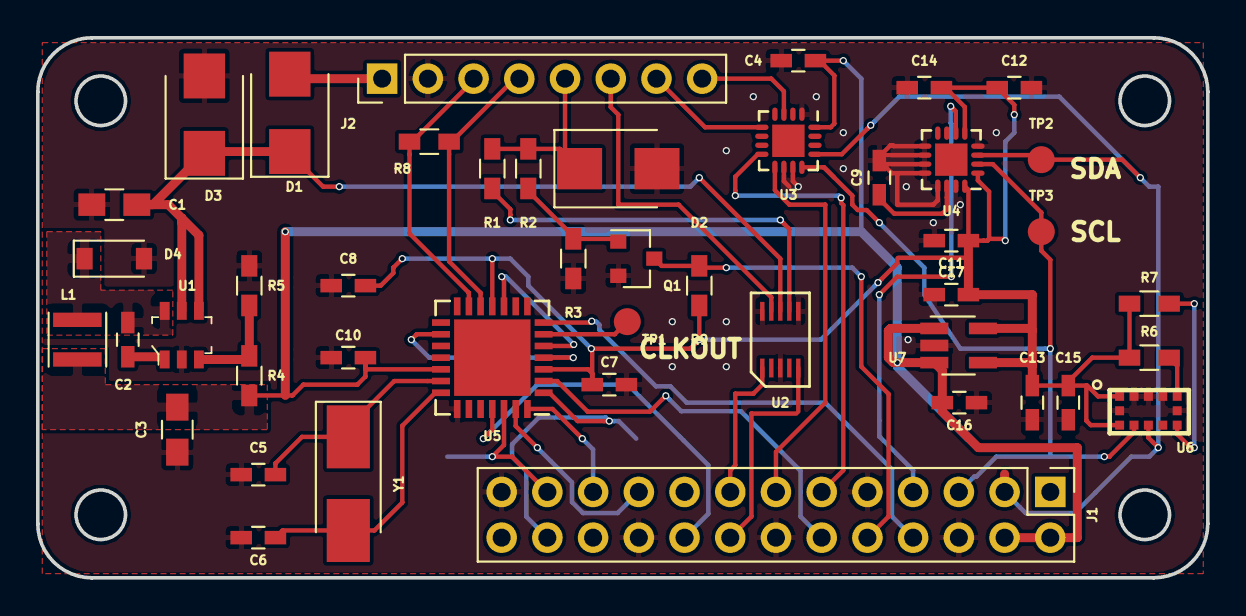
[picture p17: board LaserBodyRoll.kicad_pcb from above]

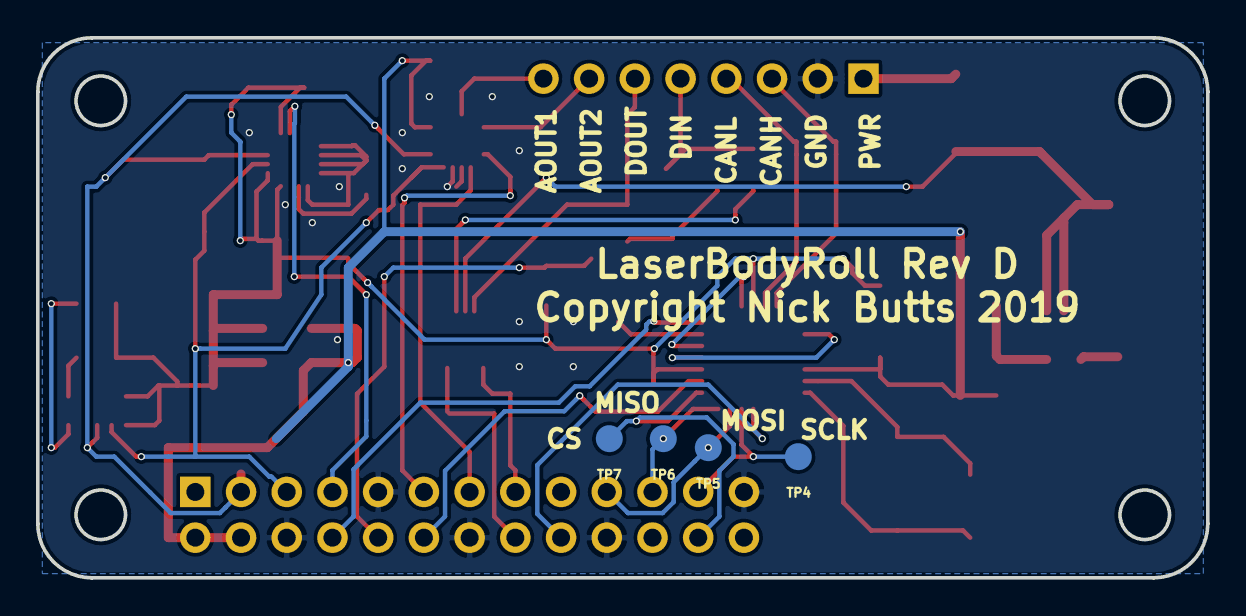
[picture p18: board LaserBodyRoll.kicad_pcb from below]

Board: 2 copper layers, 65.0 x 30.0 mm, 49 parts (4 on the bottom side), 39 nets.

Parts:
C1, C3: 10u; C_0805_HandSoldering
C2, C14: 10n; C_0603_HandSoldering
C4, C7, C8, C9, C10, C11, C13, C16, C17: 0.1u; C_0603_HandSoldering
C5, C6: 22p; C_0603_HandSoldering
C12: 2.2U; C_0603_HandSoldering
C15: 4.7u; C_0603_HandSoldering
D1: STPS2L40; D_SMB
D2, D3: D_TVS; D_SMB
D4: D_Schottky; D_SOD-123
J1: Conn_02x13_Odd_Even; Pin_Header_Straight_2x13_Pitch2.54mm
J2: Conn_01x08; Pin_Header_Straight_1x08_Pitch2.54mm
L1: 4.7u; L_Taiyo-Yuden_MD-3030
Q1: Q_NPN_BCE; SOT-23
R1, R2, R3: 24.3k; R_0603_HandSoldering
R4: 49.9k; R_0603_HandSoldering
R5: 9.53k; R_0603_HandSoldering
R6, R7: 10k; R_0603_HandSoldering
R8: 120; R_0603_HandSoldering
R9: 1k; R_0603_HandSoldering
TP1, TP2, TP3, TP4, TP5, TP6, TP7: TestPoint; Measurement_Point_Round-SMD-Pad_Small
U1: AOZ1280CI; SOT-23-6
U2: ITS42K5D; PG-TSON-10
U3: MCP47X; QFN-16-1EP_3x3mm_Pitch0.5mm
U4: ICM-20602; QFN-16-1EP_3x3mm_Pitch0.5mm
U5: MCP25625; QFN-28-1EP_6x6mm_Pitch0.65mm
U6: VL53L0X; VL53L0x
U7: LD3985; SOT-23-5_HandSoldering
Y1: 16MHz; Crystal_SMD_5032-2pin_5.0x3.2mm_HandSoldering

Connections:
12V: C1.1, D1.1, D3.1, U1.4, U1.5, U2.8
+5V: C3.1, C4.1, C10.2, C16.2, J1.2, J1.4, L1.2, R4.1, U3.16, U5.19, U7.1, U7.3
/12V_PULLUP: R1.2, U2.7
/ANA_OUT1: J2.8, U3.3
/ANA_OUT2: J2.7, U3.5
/CANH: J2.3, R8.1, U5.13
/CANL: J2.4, R8.2, U5.12
/DIN: D2.1, J2.5, R1.1, R2.1
/DOUT: J2.6, U2.9
/VL53L0X_GP: R7.2, U6.7
/VL53L0X_XSHUT: R6.2, U6.5
BCM4: J1.7, U4.6
BCM14: J1.8, U5.7
BCM15: J1.10, Q1.3, R9.2
BCM17: J1.11, U3.8
BCM18: J1.12, U5.2
BCM22: J1.15, U2.1
BCM23: J1.16, U2.5
BCM24: J1.18, U5.25
BCM27: J1.13, U3.9
GND: C1.2, C3.2, C4.2, C5.2, C6.2, C7.2, C8.2, C9.2, C10.1, C11.2, C12.2, C13.2, C14.2, C15.2, C16.1, C17.1, D2.2, D3.2, D4.2, J1.6, J1.9, J1.14, J1.20, J1.25, J2.2, Q1.2, R3.2, R5.2, U1.2, U2.3, U2.6, U2.10, U3.1, U3.10, U3.11, U4.4, U4.9, U4.10, U4.11, U4.12, U4.13, U4.15, U5.18, U5.22, U6.2, U6.3, U6.4, U6.6, U6.12, U7.2
unnamed: C2.1, D4.1, L1.1, U1.6
unnamed: C2.2, U1.1
unnamed: C5.1, U5.20, Y1.1
unnamed: C6.1, U5.21, Y1.2
unnamed: C9.1, U4.14
unnamed: Q1.1, R2.2, R3.1
unnamed: R4.2, R5.1, U1.3
unnamed: TP1.1, U5.6
unnamed: U5.5, U5.10
unnamed: U5.4, U5.16
PI_CLK: J1.23, TP4.1, U5.26
PI_MISO: J1.21, TP6.1, U5.28
PI_MOSI: J1.19, TP5.1, U5.27
PI_NSS: J1.24, TP7.1, U5.1
SCL: J1.5, TP3.1, U3.12, U4.2, U6.10
SDA: J1.3, TP2.1, U3.13, U4.3, U6.9
VCC: C7.1, C8.1, C11.1, C12.1, C13.1, C14.1, C15.1, C17.2, R6.1, R7.1, R9.1, U4.1, U4.5, U4.16, U5.3, U5.11, U6.1, U6.11, U7.4, U7.5
VIN: D1.2, J2.1

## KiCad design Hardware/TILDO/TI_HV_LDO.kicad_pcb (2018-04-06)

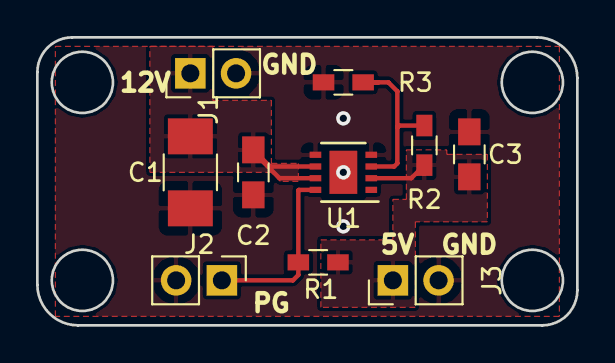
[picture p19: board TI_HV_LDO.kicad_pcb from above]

Board: 2 copper layers, 30.0 x 16.0 mm, 10 parts (0 on the bottom side), 5 nets.

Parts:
C1: 22u; C_1210_HandSoldering
C2, C3: 10u; C_0805_HandSoldering
J1, J2, J3: Conn_01x02; Pin_Header_Straight_1x02_Pitch2.54mm
R1, R3: 10k; R_0603_HandSoldering
R2: 30k; R_0603_HandSoldering
U1: TPS7A19; DFN-8-1EP_3x3mm_Pitch0.65mm

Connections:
GND: C1.2, C2.2, C3.2, J1.2, J2.2, J3.2, R3.2, U1.4, U1.5, U1.9
unnamed: C1.1, C2.1, J1.1, U1.6, U1.7
unnamed: C3.1, J3.1, R1.2, R2.1, U1.2
unnamed: J2.1, R1.1, U1.8
unnamed: R2.2, R3.1, U1.3

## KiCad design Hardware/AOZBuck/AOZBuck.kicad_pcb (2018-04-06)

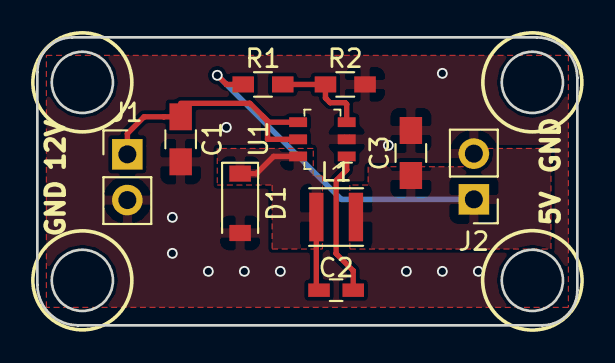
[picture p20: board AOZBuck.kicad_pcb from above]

Board: 2 copper layers, 30.0 x 16.0 mm, 10 parts (0 on the bottom side), 6 nets.

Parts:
C1, C3: 10u; C_0805_HandSoldering
C2: 10n; C_0603_HandSoldering
D1: D_Schottky; D_SOD-123
J1, J2: Conn_01x02; Pin_Header_Straight_1x02_Pitch2.54mm
L1: 4.7u; L_Taiyo-Yuden_MD-3030
R1: 49.9k; R_0603_HandSoldering
R2: 9.53k; R_0603_HandSoldering
U1: AOZ1280CI; SOT-23-6

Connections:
GND: C1.2, C3.2, D1.2, J1.2, J2.2, R2.2, U1.2
unnamed: C1.1, J1.1, U1.4, U1.5
unnamed: C2.1, D1.1, L1.1, U1.6
unnamed: C2.2, U1.1
unnamed: C3.1, J2.1, L1.2, R1.1
unnamed: R1.2, R2.1, U1.3

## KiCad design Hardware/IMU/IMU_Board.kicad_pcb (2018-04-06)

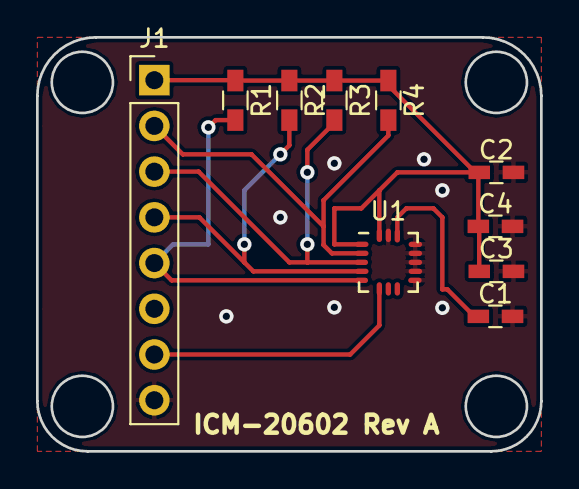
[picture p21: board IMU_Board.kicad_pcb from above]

Board: 2 copper layers, 28.0 x 23.0 mm, 10 parts (0 on the bottom side), 8 nets.

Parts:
C1, C2: 0.1u; C_0603_HandSoldering
C3: 2.2U; C_0603_HandSoldering
C4: 10n; C_0603_HandSoldering
J1: Conn_01x08; Pin_Header_Straight_1x08_Pitch2.54mm
R1, R2, R3, R4: 10K; R_0603_HandSoldering
U1: ICM-20602; QFN-16-no_center_3x3mm_Pitch0.5mm

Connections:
GND: C1.2, C2.2, C3.2, C4.2, J1.8, U1.9, U1.10, U1.11, U1.12, U1.13, U1.15
unnamed: C1.1, U1.14
unnamed: J1.2, R4.2, U1.2
unnamed: J1.3, R3.2, U1.3
unnamed: J1.4, R2.2, U1.4
unnamed: J1.5, R1.2, U1.5
unnamed: J1.7, U1.6
VCC: C2.1, C3.1, C4.1, J1.1, R1.1, R2.1, R3.1, R4.1, U1.1, U1.16

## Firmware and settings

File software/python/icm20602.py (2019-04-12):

#!/usr/bin/python3
import smbus
import time

class ICM20602():
    def __init__(self, address):
        """Initialized the ICM20602 to 10 Hz mode

        Args:
            address (int): I2C address of the DAC.
        """
        self.address = address
        self.bus = smbus.SMBus(1)
        self.packet_size = int(14)

        #DEVICE RESET -- Set bit 7 of PWR_MGMT_1 to High to reset registers to default
        success = False
<<<<<<< HEAD
        while success == False:
            time.sleep(0.1)
            try:
=======
        error = False
        while success == False:
            time.sleep(0.1)
            try:
                if error:
                    who_am_i = self.bus.read_byte_data(self.address - 1, 0x75)
>>>>>>> pi_board
                #WHO_AM_I Register -- should be x12
                who_am_i = self.bus.read_byte_data(self.address, 0x75)
                print("WHO_AM_I: {:X}".format(who_am_i))
                time.sleep(0.1)
                ret = self.bus.write_byte_data(self.address, 0x6B, 0x80)
                time.sleep(0.1)
                success = True
                pass
            except Exception as e:
                print("I2C error, retrying")
                print(e)
<<<<<<< HEAD
=======
                error = not error
>>>>>>> pi_board

        #PWR_MGMT_1 & 2 -- set 1 to x01 to wake, 2 should be x00 to ensure all sensors are on
        self.bus.write_byte_data(self.address, 0x6B, 0x01)
        pwr1 = self.bus.read_byte_data(self.address, 0x6B)
        pwr2 = self.bus.read_byte_data(self.address, 0x6C)
        print("PWR_MGMT_1: {:X}, PWR_MGMT_2: {:X}".format(pwr1, pwr2))

        #CONFIG Register -- set to x01 to signal user config and allow FIFO overwrites
        self.bus.write_byte_data(self.address, 0x1A, 0x01);
        config = self.bus.read_byte_data(self.address, 0x1A)
        print("CONFIG: {:X}".format(config))

        #FIFO_EN Register -- set to x18 to enable GYRO and ACCEL in FIFO
        self.bus.write_byte_data(self.address, 0x23, 0x18)
        fifo_en = self.bus.read_byte_data(self.address, 0x23)
        print("FIFO_EN: {:X}".format(fifo_en))

        #SMPLRT_DIV Register -- set to specified value at beginning of file
        self.bus.write_byte_data(self.address, 0x19, 99)
        smplrt = self.bus.read_byte_data(self.address, 0x19)
        print("SMPLRT_DIV: {:X}".format(smplrt))

        # Set the accelerometer sensitivity to 8g
        self.bus.write_byte_data(self.address, 0x1C, 0x08)

        # Set the low pass filter for the accelerometer
        self.bus.write_byte_data(self.address, 0x1D, 5)

        # Set the low pass filter for the gyro
        self.bus.write_byte_data(self.address, 0x1D, 5)

        # USER_CTRL Register -- set to x44 to enable FIFO operation and clear FIFO
        # will reset to x40 after clear is complete
        self.bus.write_byte_data(self.address, 0x6A, 0x44)
        user_ctrl = self.bus.read_byte_data(self.address, 0x6A)
        print("USER_CTRL: {:X}".format(user_ctrl))

    def icm_20602_dumpFIFO(self):
        timestamp = 0
        while True:
            intStatus = self.bus.read_byte_data(self.address, 0x3A)
            overflow = intStatus & 0x10;

            if overflow:
                print("!!!OVERFLOW")

            countH = self.bus.read_byte_data(self.address, 0x72)
            countL = self.bus.read_byte_data(self.address, 0x73)
            fifo_size = int((countH << 8) + countL)
            num_packets = int(fifo_size / self.packet_size)

            fepoch = time.time()
            timestamp += 1

            if num_packets > 0:
                data = self.bus.read_i2c_block_data(self.address, 0x74, int(num_packets * self.packet_size))

                for packet_index in range(num_packets):
                    offset = packet_index * self.packet_size;
                    temperature = ((int(data[offset +  6])) << 8) + data[offset +  7]
                    tempConversion = float(temperature)
                    tempConversion /= 326.8
                    tempConversion += 25

                    accelx = ((int(data[offset +  0])) << 8) + data[offset +  1]
                    accely = ((int(data[offset +  2])) << 8) + data[offset +  3]
                    accelz = ((int(data[offset +  4])) << 8) + data[offset +  5]

                    gyrox = ((int(data[offset +  8])) << 8) + data[offset +  9]
                    gyroy = ((int(data[offset + 10])) << 8) + data[offset + 11]
                    gyroz = ((int(data[offset + 12])) << 8) + data[offset + 13]

                    print("{:}, {:}, {:}, {:}, {:}, {:}, {:}, {:}, {:}, {:}, {:}".format(
                             fepoch,
                             timestamp,
                             accelx,
                             accely,
                             accelz,
                             tempConversion,
                             gyrox,
                             gyroy,
                             gyroz,
                             overflow,
                             num_packets))

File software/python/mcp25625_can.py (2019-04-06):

#!/usr/bin/python3
from gpiozero import LED
from gpiozero import Button
import time
import spidev

"""This is a class for the MCP25625 CAN controller/transceiver.
   It supports transmits, receives, configurations. It needs work.

"""
class MCP25625():
   def __init__(self, crystal, max_speed_hz, reset_pin = 18, tx_req_pin = 14, int_pin = 24):
      """Initialized object with the crystal frequency and the max SPI
      bus frequency

      Args:
         crystal (int): The frequency of the crystal attached to the controller
         max_speed_hz (int): The max speed of the SPI bus
         reset_pin (int): The BCM pin number connected to the reset line
         tx_req_pin (int): The BCM pin number connected to the Tx request line
         int_pint (int): The BCM pin number connected to the interrupt pin (input)
      """
      self.crystal = crystal
      self.reset = LED(reset_pin)
      self.TxReq = LED(tx_req_pin)
      self.CanInt = Button(int_pin)
      self.spi = spidev.SpiDev()
      self.spi.open(0, 0)
      self.spi.max_speed_hz = max_speed_hz

      self.mode_normal   = 0
      self.mode_sleep    = 1
      self.mode_loopback = 2
      self.mode_listen   = 3
      self.mode_config   = 4


   def setMode(self, mode):
      """Sets the mode of the controller, use the mode definitions above

      Args:
         mode (int): The mode definitions defined above in this class
      """
      value = mode << 5 | 0x7
      self.spi.xfer2([0x05, 0x0F, 0xFF, value])

   def resetChip(self):
      """Forces a reset of the CAN controller
      """
      self.reset.off()
      time.sleep(0.1)
      self.reset.on()

   def transmit(self):
      """Toggle the Tx request pin for Transmit object 1
      """
      self.TxReq.on()
      time.sleep(0.1)
      self.TxReq.off()

   def printStatus(self):
      """Debug function that prints the various status values of the CAN controller
      """
      # Read CANCTRL
      ret = self.spi.xfer2([0x03, 0x0F, 0x00])
      control_reg = ret[2]
      # Read Status
      ret = self.spi.xfer2([0xA0, 0x00, 0x00])
      status = ret[2]
      # Read Rx Status
      ret = self.spi.xfer2([0xB0, 0x00, 0x00])
      rx_status = ret[2]
      # Read CANSTAT
      ret = self.spi.xfer2([0x03, 0x0E, 0x00])
      canstat = ret[2]
      # Read TEC and REC
      ret = self.spi.xfer2([0x03, 0x1C, 0x00, 0x00])
      TEC = ret[2]
      REC = ret[3]

      ret = self.spi.xfer2([0x03, 0x2D, 0x00])
      errors = ret[2]

      print("CANCTRL: {:X} - CANSTATUS: {:X} - STATUS: {:X} - RX_STATUS: {:X} - TEC: {:} - REC: {:} - ERRORS: {:X}".format(control_reg, canstat, status, rx_status, TEC, REC, errors))

   def configure(self, PRSEG, PHSEG1, PHSEG2):
      """Configures the time quanta, refer to the datasheet

      Args:
         PRSEG (int): The pre sync TQ
         PHSEG1 (int): The seg 1 TQ
         PHSEG2 (int): The seg 2 TQ
      """
      # Write CNF1
      ret = self.spi.xfer2([0x05, 0x2A, 0xFF, 0xC0])
      # Write CNF2
      value = (PHSEG1 - 1) << 3 | (PRSEG - 1)
      ret = self.spi.xfer2([0x05, 0x29, 0xFF, value])
      # Write CNF3
      value = PHSEG2 - 1
      ret = self.spi.xfer2([0x05, 0x28, 0xFF, value])
      # Use B0RTSM to transmit a CAN message
      ret = self.spi.xfer2([0x05, 0x0D, 0xFF, 0x01])

   def configure_rx_masks(self):
      """This function needs more work, if configures the mask to receive all CAN messages
      """
      # Set Receive acceptance mask to 0
      ret = self.spi.xfer2([0x20, 0x20, 0x00])
      ret = self.spi.xfer2([0x20, 0x24, 0x00])
      # Setup receive buffer
      ret = self.spi.xfer2([0x20, 0x60, 0x60])

   def setTxObject(self, id, data):
      """Sets Tx object 1 with the ID and data

      Args:
         id (int): The 11-bit or 29-bit CAN id (currently only supports 11-bit)
         data (int): zero to eight bytes of data to transmit
      """
      buf = []
      buf.append(0x02)
      buf.append(0x31)
      buf.append((id >> 3) & 0xFF)
      buf.append((id & 0x07) << 5)
      buf.append(0)
      buf.append(0)
      buf.append(0x08)

      # Data
      buf.append(data[0])
      buf.append(data[1])
      buf.append(data[2])
      buf.append(data[3])
      buf.append(data[4])
      buf.append(data[5])
      buf.append(data[6])
      buf.append(data[7])
      self.spi.xfer2(buf)

   def printRxObject(self, obj):
      """Debug function to print one of the receive CAN buffers

      Args:
         obj (int): Which CAN Rx object to print
      """
      buf = []
      buf.append(0x03)
      buf.append(0x61 | obj << 5)
      for i in range(13):
         buf.append(0)
      ret = self.spi.xfer2(buf)
      canid = ret[2] << 3
      canid |= (ret[3] >> 5) & 0x7
      length = ret[6] & 0xF
      formatStr = "{:X} - ".format(canid)
      for i in range(0, length):
         formatStr = "{:} {:X}".format(formatStr, ret[7 + i])

      print(formatStr)

   def rxMessageAvailable(self):
      """Returns True if a CAN message has been received and which buffer it was received in

      Returns:
         int: -1 no message, 0 message in buffer 0, 1 message in buffer 1
      """

      # Read Rx Status
      ret = self.spi.xfer2([0xB0, 0x00, 0x00])
      rx_status = ret[2]
      if (rx_status & 0x80):
         return 0
      elif (rx_status & 0x40):
         return 1
      return -1

   def printAddress(self, address, length):
      """Debug function that prints data from address to address + length

      Args:
         address (int): The starting address to print
         length (int): The length of registers to print
      """
      buf = []
      buf.append(0x03)
      buf.append(address)
      for i in range(length):
         buf.append(0)

      ret = self.spi.xfer2(buf)
      temp = ""
      for v in ret:
         temp = "{:} {:X}".format(temp, v)

      print(temp)

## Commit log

2017-10-18 Added the Hardware project.
    [LaserBodyRoll.kicad_pcb, LaserBodyRoll.sch, Power.sch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]
2017-10-20 Added processor.
    [LaserBodyRoll.sch, Power.sch]
2017-10-22 Added software, several new pages to the schematic.
    [IO.sch, LaserBodyRoll.sch, Power.sch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]
2017-10-23 Updated the schematic
    [IO.sch, LaserBodyRoll.sch, Power.sch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]
2017-10-25 Updated the design and added schematics.
    [IO.sch, LaserBodyRoll.sch, Power.sch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]
2017-10-26 Working on footprints.
    [IO.sch, LaserBodyRoll.sch, Power.sch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]
2017-10-27 Various updates.
    [LaserBodyRoll.kicad_pcb, Processor.sch]
2017-10-30 Assigned packages to all parts. Starting layout
    [IO.sch, Power.sch, Processor.sch]
2017-11-01 Added a mechanical directory. The design is WAY to large to fit on the same form factor as a Pi zero.
    [LaserBodyRoll.kicad_pcb, Power.sch, Processor.sch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]
2017-11-09 Updated foot prints.
    [LaserBodyRoll.kicad_pcb, Power.sch]
2017-11-09 Started to place parts.
    [LaserBodyRoll.kicad_pcb, Power.sch]
2017-11-17 Worked on placement.
    [IO.sch, LaserBodyRoll.kicad_pcb, Power.sch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]
2017-11-20 Updated the board outline and placement of parts.
    [Board Outline.FCStd, IO.sch, LaserBodyRoll.kicad_pcb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]
2017-11-22 Working on the routing.
    [FTSH-105-01-L-D-K.stp, LaserBodyRoll.kicad_pcb, Processor.sch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]
2017-11-24 Partial routing, but it is starting to look weird. I'm going to try and change the pinout of the PSoC to make routing easier.
    [LaserBodyRoll.kicad_pcb]
2017-11-24 The board is routed. Not the best routing job, but it should work.
    [LaserBodyRoll.kicad_pcb, Processor.sch]
2017-11-27 Added box and pi outlines.
    [BUD PN-1312.step, RaspberryPiZeroW.IGS, RaspberryPiZeroW.SLDPRT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]
2017-12-03 Updated part numbers
    [IO.sch, Power.sch, Processor.sch]
2017-12-28 Totally f&^% up the board. This is my attempt to fix all of those issues.
    [IO.sch, LaserBodyRoll.kicad_pcb, Processor.sch]
2018-01-02 Updated the gerber output settings.
    [LaserBodyRoll.kicad_pcb]
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2018-01-27 Added the protocol code to the PSoC.
    [LaserBodyRoll.FCStd]
2018-02-03 Initial version of the reprogramming app. It compiles and runs, now just need to connect up the SPI bus.
2018-02-11 Refactored the entire design. The schematic has all of the components.
    [IO.sch, LaserBodyRoll.sch, Logic.sch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]
2018-02-11 Worked on initial placement.
    [IO.sch, LaserBodyRoll.kicad_pcb, Logic.sch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]
2018-02-12 Removed a bunch of old files. Created a board outline based on the Bud Box PN-1321-CMB
    [Board Outline.FCStd, LaserBodyRoll.kicad_pcb, Processor.sch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]
2018-02-14 Added a script to calculate current and charge time of the supercap.
    [IO.sch, LaserBodyRoll.kicad_pcb, Logic.sch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]
2018-02-18 Finished board. Added lots of stiching vias after reading a TI app note on EMC.
    [IO.sch, LaserBodyRoll.kicad_pcb, Logic.sch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]
2018-02-18 Added a resistor for the CAN phy lines. Added test points for SPI lines.
    [LaserBodyRoll.kicad_pcb, Logic.sch]
2018-02-18 Routed test points
    [LaserBodyRoll.kicad_pcb, Logic.sch]
2018-03-01 Order this version of the board.
    [LaserBodyRoll.kicad_pcb]
2018-03-08 Fixed some pads.
    [Logic.sch, Power.sch, Processor.sch]
2018-03-11 Have a working project that blinks LEDs.
    [kalman_input1.csv, kalman_output1.csv]
2018-03-11 Major rework. Trying to get interrupts working.
    [kalman_input1.csv, kalman_output1.csv]
2018-03-12 More tweaking. I have the timers system working, but they are about 10 times too fast.
2018-03-12 Tweaks to the BLE module to get it to work.
    [BOM.xlsx]
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2018-03-23 Updates to prevent compiler warnings. Tested the Flash and that appears to work. The IMU and the Laser rangefinder are not working. Most likely not solder correctly.
2018-03-25 Everything appears to work except the IMU. I've tried to switch to I2C and I still can't talk to the part. I'm going to move on without the IMU.
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2018-03-30 Added the AOZBuck board.
    [AOZBuck.FCStd, AOZBuck.kicad_pcb, AOZBuck.sch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]
2018-04-02 Updated Buck layout.
    [AOZBuck.kicad_pcb, AOZBuck.sch, BOM.xlsx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]
2018-04-04 Created a small buck and LDO board.
    [AOZBuck.kicad_pcb, TI_HV_LDO.FCStd, TI_HV_LDO.kicad_pcb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]
2018-04-04 Add some silkscreen items
    [AOZBuck.kicad_pcb]
2018-04-04 More updates before ordering.
    [AOZBuck.FCStd, AOZBuck.kicad_pcb, AOZBuck1.step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]
2018-04-06 Checked in some new power boards and a stand alone IMU board.
    [AOZ1280 Design Note.xlsx, CLV1AFKB(Светодиод RGB).STEP, IMU_Board.FCStd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]
2018-07-26 Added a bunch of the mechanical designs.
    [AOZBuck.FCStd, AOZBuck1.SLDPRT, AOZBuck1.step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]
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2019-01-20 Added the hardware design info.
    [BOM.csv, Bottom PCB Holder.SLDPRT, Bottom PCB Holder.STL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]
2019-01-21 Updated the BLE app. It blinks an LED at 1 Hz at the moment.
    [AOZBuck1.SLDPRT, Base.sldprt]
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2019-02-09 Added some libraries and mechanical drawings for the box.
    [AOZ1280 Design Note.xlsx, Bottom PCB Holder v2.SLDPRT, Bottom PCB Holder v2.STL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]
2019-02-09 Added a system BOM
    [System BOM.xlsx]
2019-02-17 Working on a redesigned board.
    [Bottom PCB Holder v2.SLDPRT, Bottom PCB Holder v2.STL, IO.sch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]
2019-02-17 Big refactor, got rid of all software. Everything will run on the Pi.
    [LaserBodyRoll.kicad_pcb, LaserBodyRoll.sch]
2019-02-18 Added an LDO to power this board.
    [LaserBodyRoll.kicad_pcb, LaserBodyRoll.sch]
2019-03-29 Added rescued parts.
    [BOM.csv, BOM.xlsx]
2019-03-29 Saved the schematic.
    [LaserBodyRoll.sch]
2019-04-06 Moved the CAN and DAC into classes. The IO is basic enough that it doesn't need a class.
    [mcp25625_can.py, mcp47Cx_dac.py, test.py]
2019-04-07 Added the icm20602 code and some test code. It keeps timing out via I2C.
2019-04-12 Added the rescue backend stuff.
    [IO-2019-01-20-17-04-19.sch, IO-2019-01-27-18-35-42.sch, IO-2019-01-27-18-44-06.sch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]

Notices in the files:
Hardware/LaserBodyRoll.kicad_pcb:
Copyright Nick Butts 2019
